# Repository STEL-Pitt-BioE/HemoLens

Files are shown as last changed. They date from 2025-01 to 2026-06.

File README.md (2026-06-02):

# HemoLens

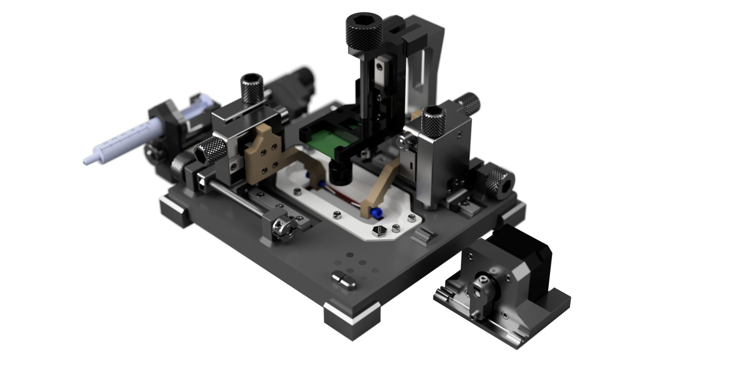
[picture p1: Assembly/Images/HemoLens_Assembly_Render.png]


HemoLens is an **open source** pressure myograph system and cardiac flow simulator for mechanical evaluation of native and tissue engineered blood vessels under static and dynamic pressures. 

Our platform offers a comprehensive, open-source pacakge for industry-standard vasculature research. We've achieved this all for ~2% the cost of commercial systems.

This platform was developed at the University of Pittsburgh's Shiwarski Tissue Engineerng Laboratory (STEL). You can find our lab [here.](https://shiwarskilab.com/)

## Paper
https://www.sciencedirect.com/science/article/abs/pii/S2666998625003096

## Interactive Model
You can find an **online assembly file** [here.](https://andrew1492.autodesk360.com/g/shares/SH286ddQT78850c0d8a4ab926256a7c2b0b3)

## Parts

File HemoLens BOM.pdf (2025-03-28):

Designator | Component | Number of Units | Total Cost | Units/pack age | Cost Per Unit [USD] | Total Cost [USD] | Source of Materials
Prusament PLA Galaxy Black | 2258572 | 0.43 | $ 29.99 | 1 | $ 29.99 | $ 12.82 | Prusa
Prusament PETG Galaxy Black | 4715597 | 0.04 | $ 29.99 | 1 | $ 29.99 | $ 1.15 | Prusa
M6 x 1 mm, 60mm long, Fully Threaded Hex Cap | 91280A074 | 4 | $ 9.79 | 50 | $ 0.20 | $ 0.78 | McMaster
Flanged, Oil-Embedded Sleeve Bearing for 6mm Shaft | 6659K672 | 16 | $ 3.05 | 1 | $ 3.05 | $ 48.80 | McMaster
50 mm MGN9 Linear Rail | B0D3T1MXKX | 5 | $ 15.99 | 1 | $ 15.99 | $ 79.95 | Amazon
150 mm MGN9 Linear Rail | 3547313MTE | 2 | $ 15.58 | 1 | $ 15.58 | $ 31.16 | Amazon
M6 Hex Socket Set Screw Collar | 6056N14 | 4 | $ 2.08 | 1 | $ 2.08 | $ 8.32 | McMaster
M6 x 1 mm, Medium-Strength Steel Hex Nut | 90592A016 | 6 | $ 5.21 | 100 | $ 0.05 | $ 0.31 | McMaster
M3 x 0.5 mm, Low-Strength Steel Hex Nut | 90591A250 | 18 | $ 2.81 | 100 | $ 0.03 | $ 0.51 | McMaster

M3 x 0.5 mm,
Medium-Strength
Steel Thin Hex
Nut
90695A033 | 2 | $ | 4.23 | 100 | $ | 0.04 | $ | 0.08 | McMaster
M3 x 0.5 mm, 8mm long, Fully Threaded Socket Cap | 91290A113 | 12 | $ 12.52 | 100 | $ 0.13 | $ 1.50 | McMaster
M3 x 0.5 mm, 6mm long, Fully Threaded Socket Cap | 91290A111 | 30 | $ 11.32 | 100 | $ 0.11 | $ 3.40 | McMaster
M3 x 0.5 mm, 4mm long, Fully Threaded Socket Cap | 91290A109 | 36 | $ 13.48 | 100 | $ 0.13 | $ 4.85 | McMaster
M8 x 1.25 mm, Medium-Strength Steel Hex Nut | 90591A161 | 1 | $ 6.91 | 100 | $ 0.07 | $ 0.07 | McMaster
M8 Clamping Two-Piece Shaft Collar | 6063K14 | 1 | $ 9.93 | 2 | $ 4.97 | $ 4.97 | McMaster
M8 x 1.25 mm, 130mm long, Fully Threaded Hex Cap | 91287A463 | 1 | $ 3.50 | 1 | $ 3.50 | $ 3.50 | McMaster
Small Circular Neodymium Magnets | B0CCXY6WBR | 56 | $ 6.99 | 240 | $ 0.03 | $ 1.63 | Amazon

Rectangular
Neodymium
Magnets
6x3x2-150p` | 4 | $ | 8.99 | 150 | $ | 0.06 | $ | 0.24 | Amazon
100 mm MG9N Carriage and Rail | B09SD9GXVP | 1 | $ 16.89 | 1 | $ 16.89 | $ 16.89 | Amazon
Nema 17 Stepper Motor | B0CDRMHM82 | 1 | $ 15.98 | 1 | $ 15.98 | $ 15.98 | Amazon
M3 Stainless Steel Ball Bearing | 4668K216 | 2 | $ 24.14 | 1 | $ 24.14 | $ 48.28 | McMaster
Arducam USB Camera | B096M5DKY6 | 1 | $ 49.99 | 1 | $ 49.99 | $ 49.99 | Amazon
M2 x 0.4 mm, Medium-Strength Steel Hex Nut | 90591A265 | 4 | $ 2.22 | 100 | $ 0.02 | $ 0.09 | McMaster
M2 x 0.4 mm, 8mm long, Fully Threaded Socket Cap | 91290A015 | 4 | $ 18.76 | 100 | $ 0.19 | $ 0.75 | McMaster
M12 Lens | B09W5KCNHK | 1 | $ 16.00 | 1 | $ 16.00 | $ 16.00 | Amazon
M6 Two-Piece Shaft Collar | 6063K13 | 1 | $ 9.45 | 2 | $ 4.73 | $ 4.73 | McMaster
M6 x 1 mm, 90mm long, Fully Threaded Hex Cap | 91287A358 | 1 | $ 13.57 | 10 | $ 1.36 | $ 1.36 | McMaster

M6 x 1 mm,
Medium-Strength
Steel Hex Nut
90591A151 | 1 | $ | 3.14 | 100 | $ | 0.03 | $ | 0.03 | McMaster
75 x 25 mm Fischerbrand Glass Microscope Slide | 12-550-A3 | 1 | $ 85.00 | 144 | $ 0.59 | $ 0.59 | Fischer
75 x 25 mm Rubber Gasket | B0B5V95MRG | 0.03 | $ 9.99 | 1 | $ 9.99 | $ 0.30 | Amazon
M3 x 0.5 mm Heat-Set Inserts for Plastic | 94180A331 | 8 | $ 20.44 | 100 | $ 0.20 | $ 1.64 | McMaster
M3 Stainless Steel Washer | 93475A210 | 1 | $ 2.19 | 100 | $ 0.02 | $ 0.02 | McMaster
M6 x 1 mm 100mm long, Fully Threaded Hex Cap | 91287A361 | 2 | $ 14.31 | 10 | $ 1.43 | $ 2.86 | McMaster
M6 x 1 mm Medium-Strength Steel Hex Nut | 90591A151 | 2 | $ 3.14 | 100 | $ 0.03 | $ 0.06 | McMaster
Plastic Barbed Tube Fitting | 5117K85 | 2 | $ 14.69 | 10 | $ 1.47 | $ 2.94 | McMaster
16 mm (Outer-Diameter Rubber) Grommet | B09XVDTQ8F | 4 | $ 8.59 | 125 | $ 0.07 | $ 0.27 | Amazon
ELEGOO Mega | B01H4ZDYCE | 1 | $ 22.99 | 1 | $ 22.99 | $ 22.99 | Amazon

YUNBO 12V 3A
Power Supply
B07K225RR3 | 1 | $ | 12.99 | 1 | $ | 12.99 | $ | 12.99 | Amazon
DRV8825 and A4988 Stepper Motor Driver | B0CD6VRCGJ | 1 | $ 9.99 | 5 | $ 2.00 | $ 2.00 | Amazon
Wheatstone Amplifier Shield | RBC-Onl-38 | 1 | $ 58.28 | 1 | $ 58.28 | $ 58.28 | RobotShop
L298N Motor Driver Board | B0CR6BX5QL | 1 | $ 6.99 | 2 | $ 3.50 | $ 3.50 | Amazon
DOMICA Small-Volume Aquarium Pump | B0892DKNR3 | 1 | $ 8.99 | 1 | $ 8.99 | $ 8.99 | Amazon
Gikfun Mcro Peristaltic Pumps | GK1028 | 1 | $ 19.98 | 2 | $ 9.99 | $ 9.99 | Amazon
Stepper Motor Cable | B0CMQN8L5R | 1 | $ 8.99 | 4 | $ 2.25 | $ 2.25 | Amazon
4 Pin Dupont Cable | 8541684769 | 1 | $ 7.99 | 10 | $ 0.80 | $ 0.80 | Amazon
Flow-Through Pressure Sensor | 26PCDFG5G | 2 | $ 88.67 | 1 | $ 88.67 | $ 177.34 | Honeywell
Plastic Submersible Cord Grip | 69915K11 | 1 | $ 3.85 | 1 | $ 3.85 | $ 3.85 | McMaster
Quick and Secure Connect Terminal Block | 8841T11 | 1 | $ 1.87 | 1 | $ 1.87 | $ 1.87 | McMaster
HiLetgo 1602 LCD Keypad Shield | B00OGYXN8C | 1 | $ 7.99 | 1 | $ 7.99 | $ 7.99 | Amazon

1/16”‎ID‎Silicone‎
Tubing
B0915Z455G | 0.025 | $ | 7.99 | 1 | $ | 7.99 | $ | 0.20 | Amazon
IVYX Scientific Digital Water Bath | B07T81P5KN | 1 | $ 49.99 | 1 | $ 49.99 | $ 49.99 | Amazon
BD syringe | 309657 | 1 | $ 38.75 | 200 | $ 0.19 | $ 0.19 | Fisher
30-Gauge needle | JG30-0.5HPX | 2 | $ 26.60 | 50 | $ 0.53 | $ 1.06 | Jenson Global

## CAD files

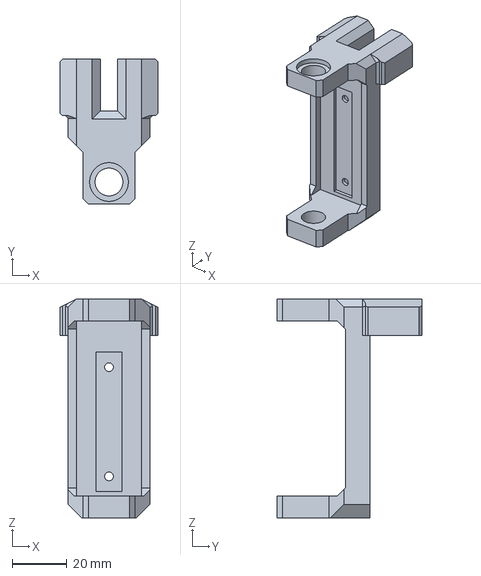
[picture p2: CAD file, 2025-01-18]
Assembly/Camera Gantry/STEP Files/Camera_Main.step
36.0 x 53.0 x 80.2 mm

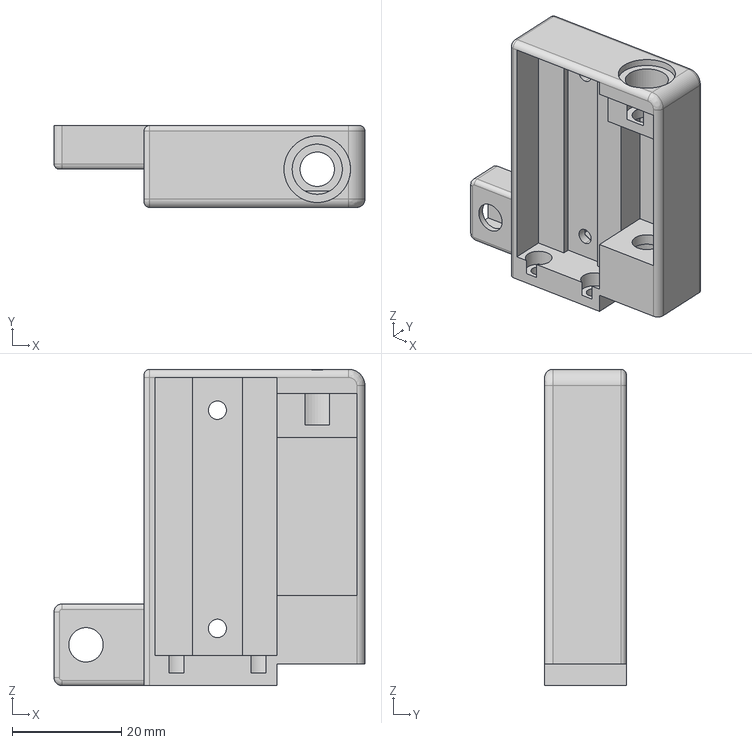
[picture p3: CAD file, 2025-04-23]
Assembly/Micromanipulators/STEP Files/Manipulator_Main_Bracket.step
57.0 x 15.0 x 58.0 mm

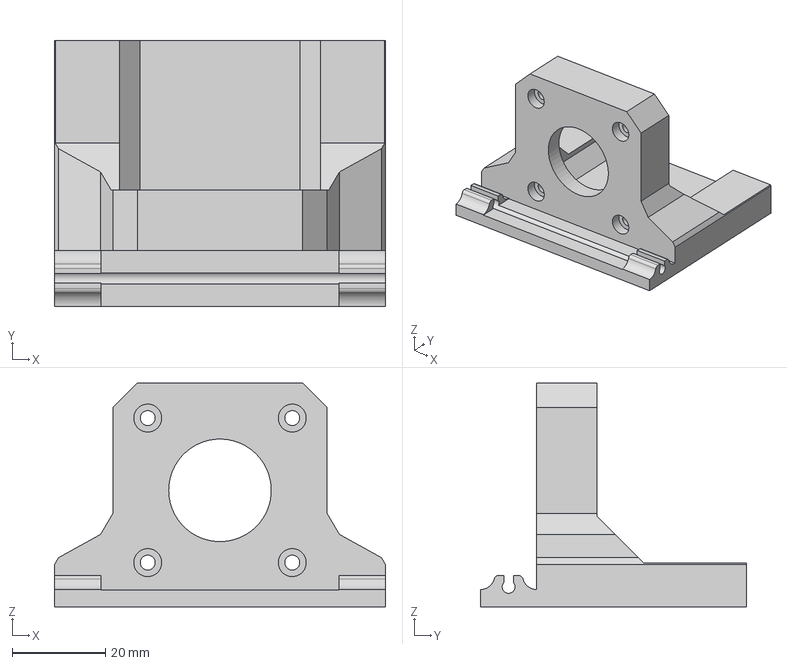
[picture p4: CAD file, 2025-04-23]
Assembly/RAMP/STEP Files/RAMP_Main.step
71.0 x 57.0 x 48.0 mm

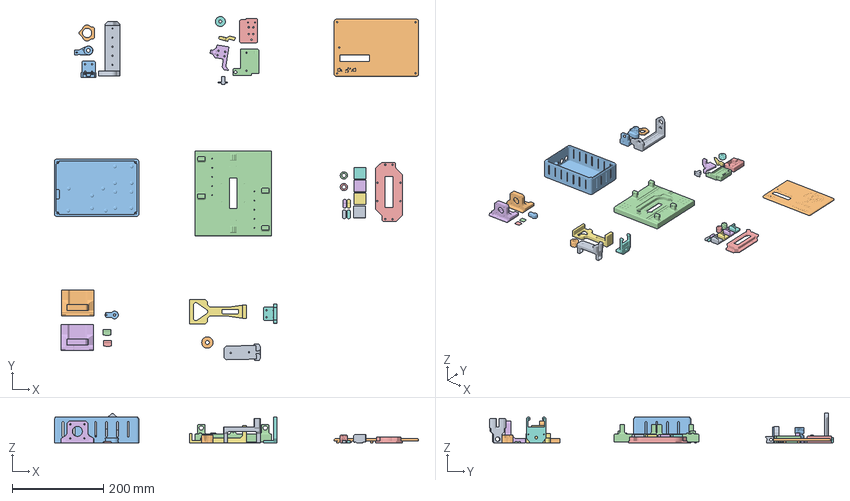
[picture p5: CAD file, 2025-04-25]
HemoLens_Full_Build_Plate.3mf
798.9 x 754.3 x 64.7 mm
Syringe Cover v5.stl
Ratchet v28.stl
z_assem.stl
y_assem_micro.stl
manip_arm_base.stl
manip_arm.stl
k_head.stl
Z_Axis_Accessory.stl
Completed Lid.stl
HemoLens_Enclosure_Base.step
full_craddle.stl
Insert v25.stl
feet.stl x 4
ramp_base.stl
occ_arm.stl
RAMP 80-120 mmHg Adapter
RAMP 80-145+ mmHg Adapter.step
RAMP_Main.step
Test Bracket v6.stl
Z Stage v19.stl
gantry_z_mount.stl
M6_Knurl_Large.step
Ratchet_Syringe_Holder.step
M6_Knurl.step x 2
Tubing_Holder.step x 4

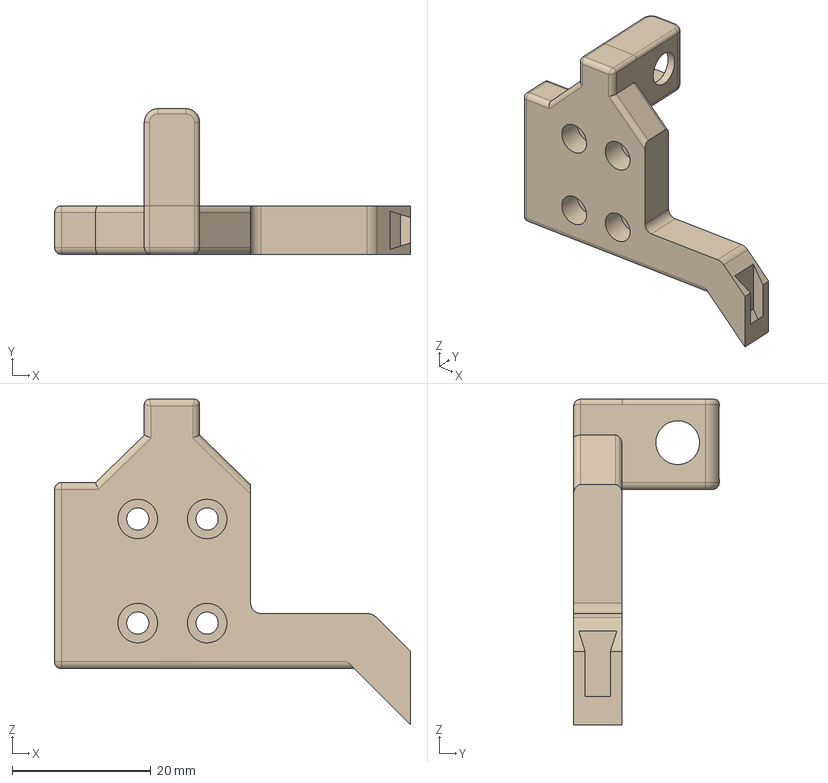
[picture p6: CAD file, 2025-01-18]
Assembly/Micromanipulators/STEP Files/Cannula_Main.step
51.3 x 21.0 x 46.9 mm

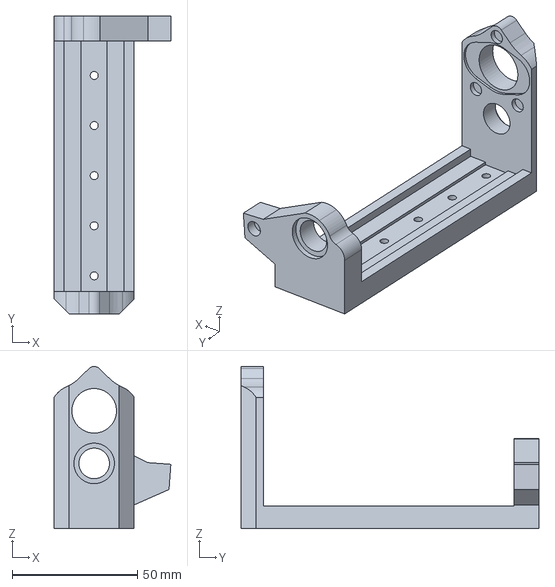
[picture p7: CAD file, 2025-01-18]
Assembly/Pressure Crank/STEP Files/iRPS_Main.step
46.6 x 119.0 x 64.7 mm

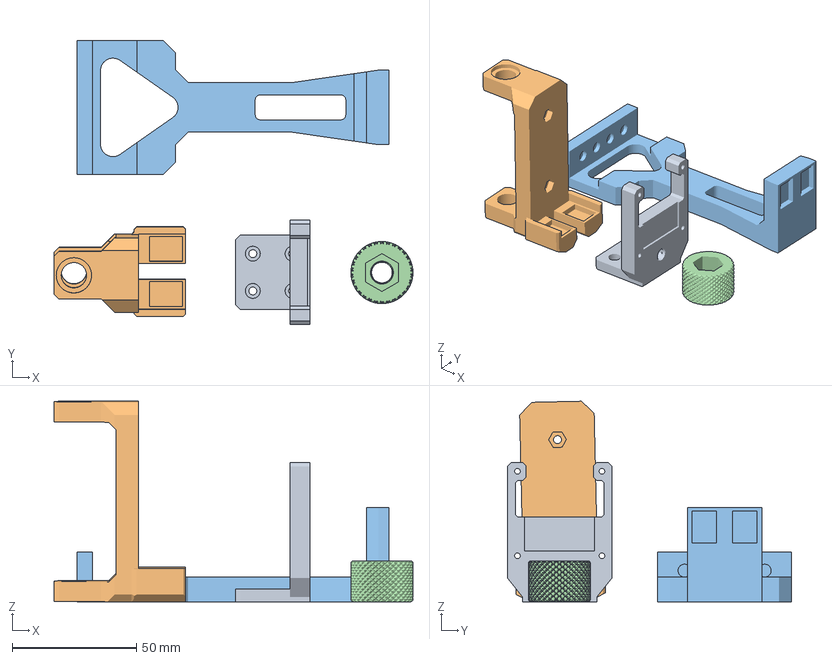
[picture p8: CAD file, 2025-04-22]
Assembly/Camera Gantry/Camera_Print_Plate.3mf
144.4 x 114.3 x 80.7 mm
Z Stage v19.stl
gantry_z_mount.stl
Camera_Bracket.stl
M6_Knurl_Thumb.stl

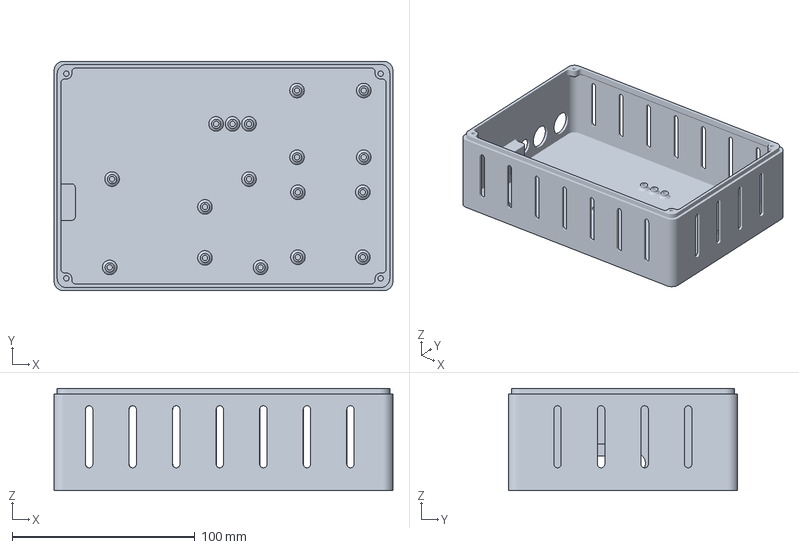
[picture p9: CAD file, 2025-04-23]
Assembly/Electronics Enclosure/Enclosure_Base_Plate.3mf
185.4 x 125.5 x 56.0 mm

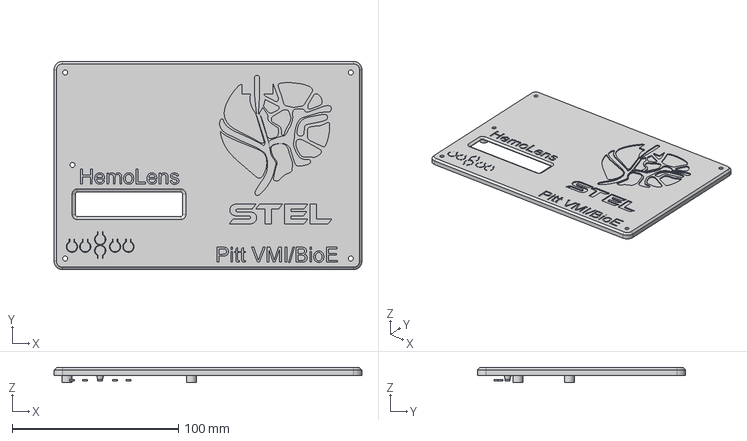
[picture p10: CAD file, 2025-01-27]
Assembly/Electronics Enclosure/STEP Files/Enclosure_Lid.step
185.4 x 125.5 x 8.90 mm

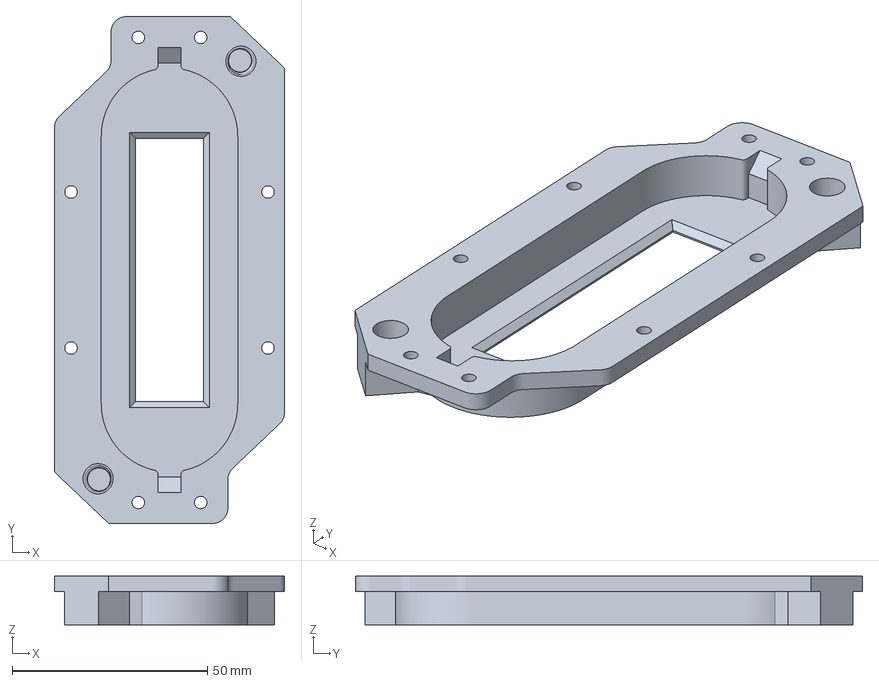
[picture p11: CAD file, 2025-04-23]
Assembly/Main Platform/Cradle_Insert_Plate.3mf
59.0 x 130.0 x 12.5 mm

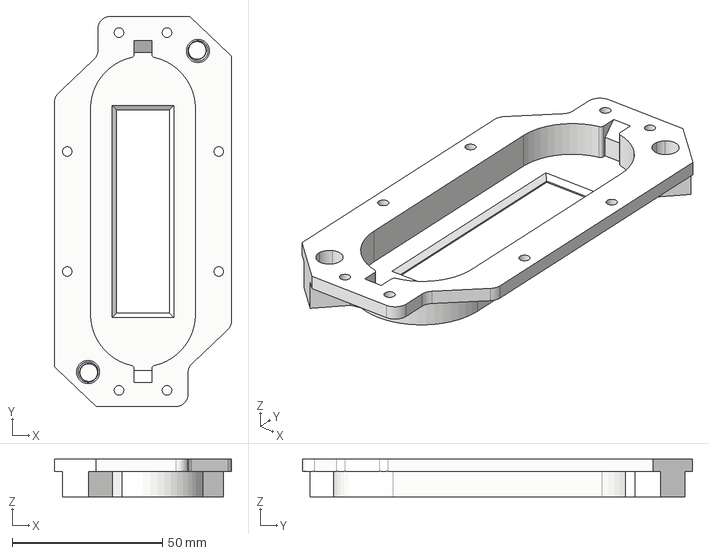
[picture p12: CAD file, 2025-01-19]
Assembly/Main Platform/STEP Files/Cradle_Insert.step
59.0 x 130.0 x 12.5 mm

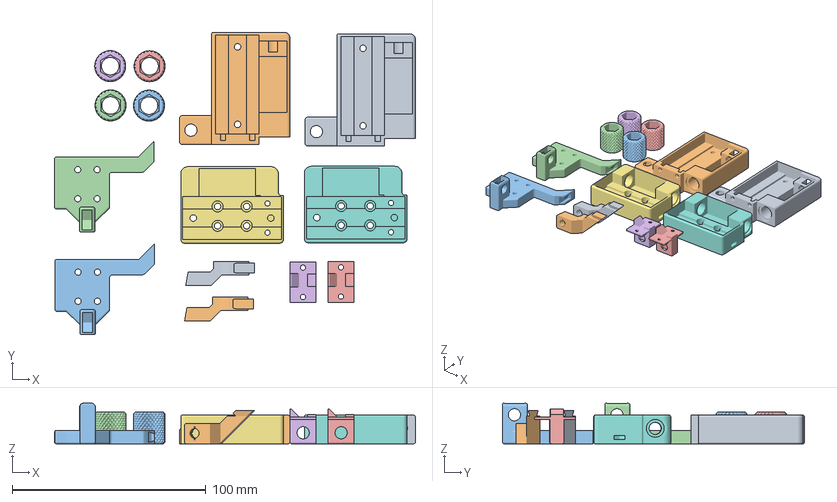
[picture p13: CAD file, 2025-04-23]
Assembly/Micromanipulators/Manipulator_Print_Plate.3mf
186.2 x 156.0 x 21.0 mm
Manipulator_Main_Bracket.step x 2
M6_Knurl.step x 4
Manipulator_Y_Axis.step x 2
Cannula_Sub.step x 2
Cannula_Main.step x 2
Z_Axis_Accessory.step x 2

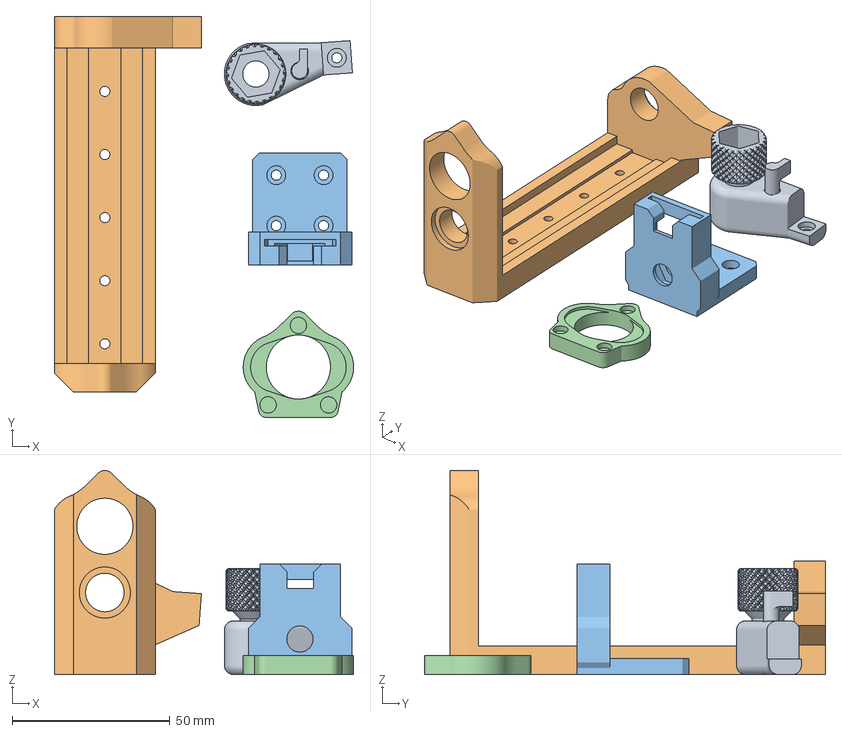
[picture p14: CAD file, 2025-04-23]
Assembly/Pressure Crank/iRPS_Print_Plate.3mf
94.9 x 127.1 x 64.7 mm
Ratchet.step
Ratchet_Main (1).step
Ratchet_Syringe_Holder.step
Syringe_Cover.step

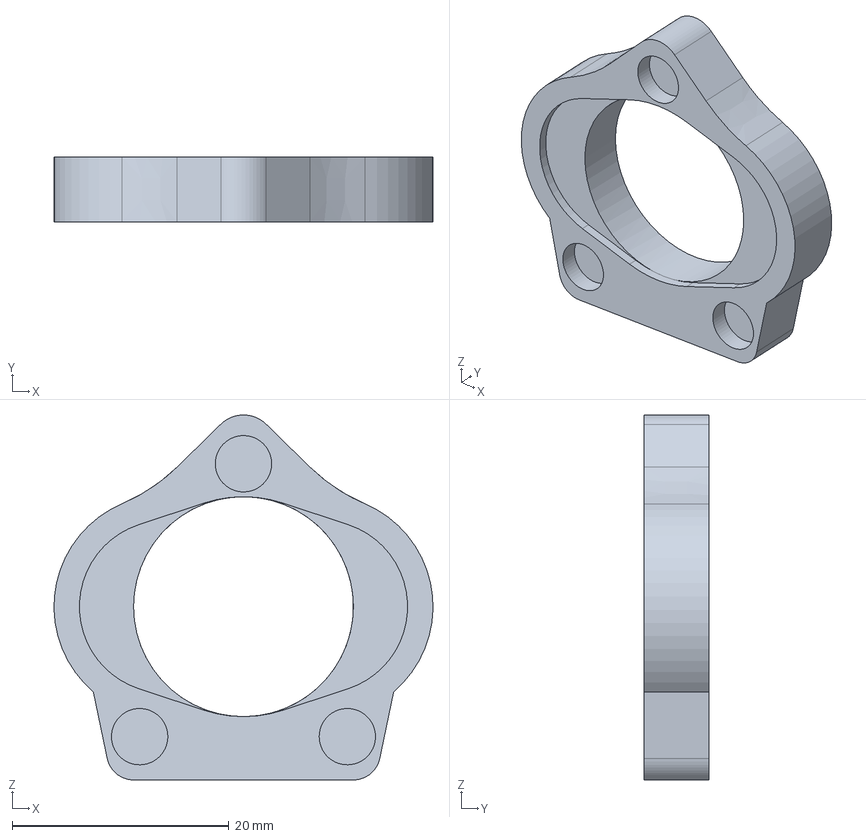
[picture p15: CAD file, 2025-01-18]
Assembly/Pressure Crank/STEP Files/Syringe_Cover.step
35.0 x 6.00 x 33.7 mm

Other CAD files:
Assembly/RAMP/RAMP_Build_Plate.3mf
Assembly/Camera Gantry/STEP Files/Camera_Bracket.step
Assembly/Electronics Enclosure/Enclosure_Lid_Plate.3mf
Assembly/Electronics Enclosure/STEP Files/Enclosure_Base.step
Assembly/Camera Gantry/STEP Files/Camera_Z_Stage.step
Assembly/Main Platform/Cradle_Plate.3mf
Assembly/Main Platform/STEP Files/Cradle.step
Assembly/Main Platform/STEP Files/Cradle_Feet.step
Assembly/Main Platform/STEP Files/Tubing_Holder.step
Assembly/Micromanipulators/STEP Files/Cannula_Sub.step
Assembly/Micromanipulators/STEP Files/Manipulator_Y_Axis.step
Assembly/Micromanipulators/STEP Files/Z_Axis_Accessory.step
Assembly/Pressure Crank/STEP Files/iRPS_Syringe_Holder.step
Assembly/Pressure Crank/iRPS_Syringe_Holder.step
Assembly/RAMP/STEP Files/RAMP 80-120 mmHg Adapter.step
Assembly/RAMP/STEP Files/RAMP 80-145+ mmHg Adapter.step
Assembly/RAMP/STEP Files/RAMP_Gate.step

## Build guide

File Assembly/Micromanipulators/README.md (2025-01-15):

HemoLens Micromanipulator
======

A low-cost micromanipulator for precise, 3-axis movement of vessel scaffolds.

## Building the VasoTracker Pressure Monitor:

Table of the components required:

**Parts**|**Supplier**|**Part #**|**Qty**|**£/unit**|**Total (£)**
:-----:|:-----:|:-----:|:-----:|:-----:|:-----:
Arduino Uno|Arduino|A000066 |1|20.7|20.7
Wheatstone Amplifier Shield|RobotShop|RB-Onl-38|1|15.11|15.11
LCD Shield|iTead Studio|1602 LCD|1|3.98|3.98
Flow through pressure transducers|Honeywell|26PCDFG5G|2|36.72|73.44
12" 4-Pin Jumper Wire|Sparkfun Electronics|PRT-10374|2|1.48|2.96
Arduino R3 Stackable Headers|Sparkfun Electronics|PRT-10007|1|1.14|1.14
LEGO™ Encolsure|LEGO|-|-|-|-
 | | | | |Subtotal|117.33

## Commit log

2025-01-20 Create Electronics Enclosure
2025-01-20 Bambu Studio Print Setup
    [HEMOLENS_ELECTRONICS_LID.3mf]
2025-01-20 Bambu example plate
    [Camera_gantery_bamabu_example_plate.3mf]
2025-01-20 Bath insert and Base feet Bambu plate example
    [insert_and_basefeet_bambu_plate.3mf]
2025-01-20 Bambu plate exmaples
    [HemoLens_Base_Bambu_Plate_Exp.3mf, insert_and_basefeet_bambu_plate.3mf]
2025-01-20 Example build plate
    [iPRS_Bambu_plate.3mf]
2025-01-20 Bambu example build plate
    [maicromanipulator_example_build_plate.3mf]
2025-01-20 Build plate examples
    [hemolens_base_build_plate.3mf, hemolens_lid_build_plate.3mf]
2025-03-18 Update and rename Manipulator_Y_Axis.step to Manipulator_X_Axis.step
    [Manipulator_X_Axis.step]
2025-04-23 Update and rename Ratchet_Syringe_Holder.step to iRPS_Syringe_Holder.step
    [iRPS_Syringe_Holder.step]
2025-04-23 Revert "Delete Assembly/Pressure Crank/iRPS_Syringe_Holder.step"
    This reverts commit 11f9f7a350f3067f1229d03533c2aae7014d0751.
    [iRPS_Syringe_Holder.step]
2025-04-23 Revert "Delete Assembly/Pressure Crank/iRPS_Main.step"
    This reverts commit 3e1cc4b6083574797b78e6a26f796bd46ff7136b.
    [iRPS_Main.step]
2025-04-23 Revert "Delete Assembly/Pressure Crank/iRPS.step"
    This reverts commit 092d5225db3029ec23bce9094bf971c2ae59a90f.
2025-04-23 Revert "Delete Assembly/Pressure Crank/Syringe_Cover.step"
    This reverts commit 1191fa0247398a125394e58c01c42b9b9514da72.
    [Syringe_Cover.step]
